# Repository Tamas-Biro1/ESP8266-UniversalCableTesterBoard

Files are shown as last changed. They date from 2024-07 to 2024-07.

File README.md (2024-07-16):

## Overview
The Universal Cable Tester Board is a tool designed to test the continuity and proper wiring layout of any cables up to 32 wires. This project includes the design schematics, PCB layout, firmware, and software for the cable tester.

This board is not a standalone device, it must be connected to a computer (running Windows) through USB cable and the [Cable Analyzer](https://github.com/david-biro/UniversalCableAnalyzer) (opensource) must run on that machine. For more details about the software, click [here](https://github.com/david-biro/UniversalCableAnalyzer).

<p align="center">
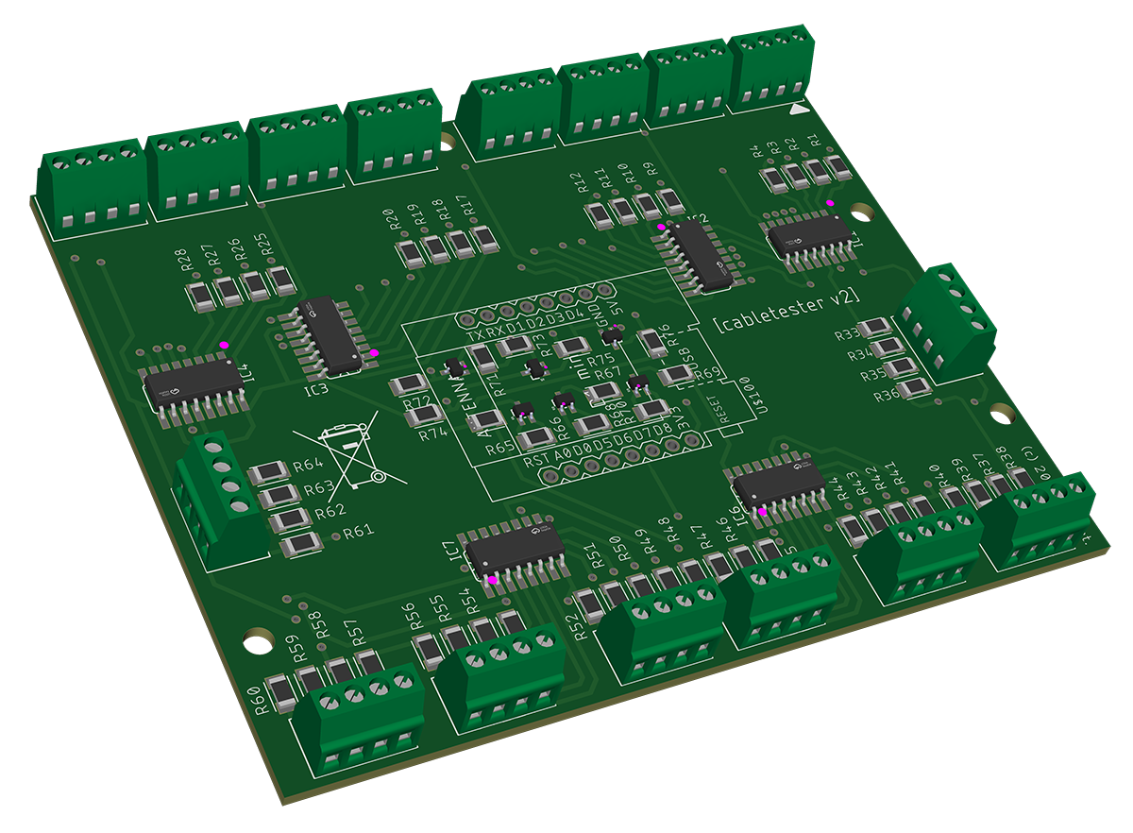
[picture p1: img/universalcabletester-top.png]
Universal Cable Tester
  
</p>

## How it works
### The hardware
The core of the Cable Tester board is a Wemos D1 Mini (ESP8266) microcontroller, which initiates the measurements, collects the test results, and sends the data back to the Cable Analyzer software running on the PC. The Cable Analyzer then evaluates the test results and visualizes them on the GUI. Communication is conducted via a USB connection, utilizing the UART port of the ESP8266, which is connected to a CH340 (or occasionally a CP2104) USB-to-Serial chip. This chip provides USB client connectivity to the ESP8266; therefore, it is required to install a serial port driver on the computer, for example from [here](http://www.wch-ic.com/downloads/CH341SER_ZIP.html).

The measuring mechanism is very simple: when the Cable Tester board receives the `<START>` string via serial, the microcontroller loops through the pins from 1 to 32 and applies 5V to them one by one. In every cycle, it measures and collects the response from the other side accordingly. When it reaches the last pin, it sends the result back to the Cable Tester application to evaluate and visualize.

Example cable layout and its serial output:
<p align="center">
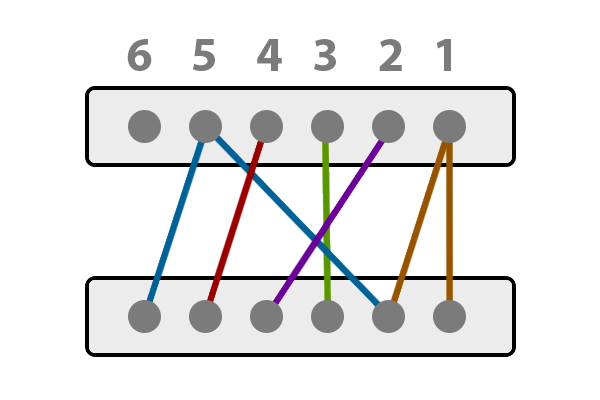
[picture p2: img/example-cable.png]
Universal Cable Tester
  
</p>

  ```
  <RESULT,3,8,4,16,34,0,0,0,0,0,0,0,0,0,0,0,0,0,0,0,0,0,0,0,0,0,0,0,0,0,0,0>
  ```
_Explanation:_ The output string is a comma-separated list of 32-bit integers containing the results for the pins from 1 to 32, listed from left to right respectively. By taking the binary representation of each value, the cable layout can be verified. See:

```
pin:                       [32]                             [1]  
                                       (binary)                  (decimal)
request sent on "A" side:  00000000 00000000 00000000 00000001       1
response got on "B" side:  00000000 00000000 00000000 00000011       3

request sent on "A" side:  00000000 00000000 00000000 00000010       2
response got on "B" side:  00000000 00000000 00000000 00001000       8

request sent on "A" side:  00000000 00000000 00000000 00000100       4
response got on "B" side:  00000000 00000000 00000000 00000100       4

request sent on "A" side:  00000000 00000000 00000000 00001000       8
response got on "B" side:  00000000 00000000 00000000 00010000       16

request sent on "A" side:  00000000 00000000 00000000 00010000       16
response got on "B" side:  00000000 00000000 00000000 00100010       34

request sent on "A" side:  00000000 00000000 00000000 00100000       32
response got on "B" side:  00000000 00000000 00000000 00000000       0

...

request sent on "A" side:  10000000 00000000 00000000 00000000   2147483648
response got on "B" side:  00000000 00000000 00000000 00000000       0
```

To understand this circuit, [here](https://wokwi.com/projects/403145055048695809) is an Arduino playground on **Wokwi** which simulates a straight cable (where pin 1 is connected to pin 1, pin 2 to pin 2, etc.). For better visualization, the wire "connections" are interrupted by LEDs, so when they flash, it means the checking is actually taking place.

Due to the lack of pins on ESP8622, shift registers are used on both side. On the `write` (or "A" side) 4 pcs of [74HC595](https://www.diodes.com/assets/Datasheets/74HC595.pdf) 8-bit serial-in/parallel-out shift registers are used in daisy chain to get 32-bit parallel output from the 32-bit serial input on the DS pin. On the `read` (or "B" side) 4 pcs of [74HC165](https://www.sparkfun.com/datasheets/Components/General/sn74hc165.pdf) parallel-in/serial-out shift registers are used. Between the `write` side and the green terminal blocks, 8 pcs of [IS281-4](https://docs.rs-online.com/c7c9/0900766b81617f80.pdf) NPN type optocouplers are used to isolate wires. 

<p align="center">
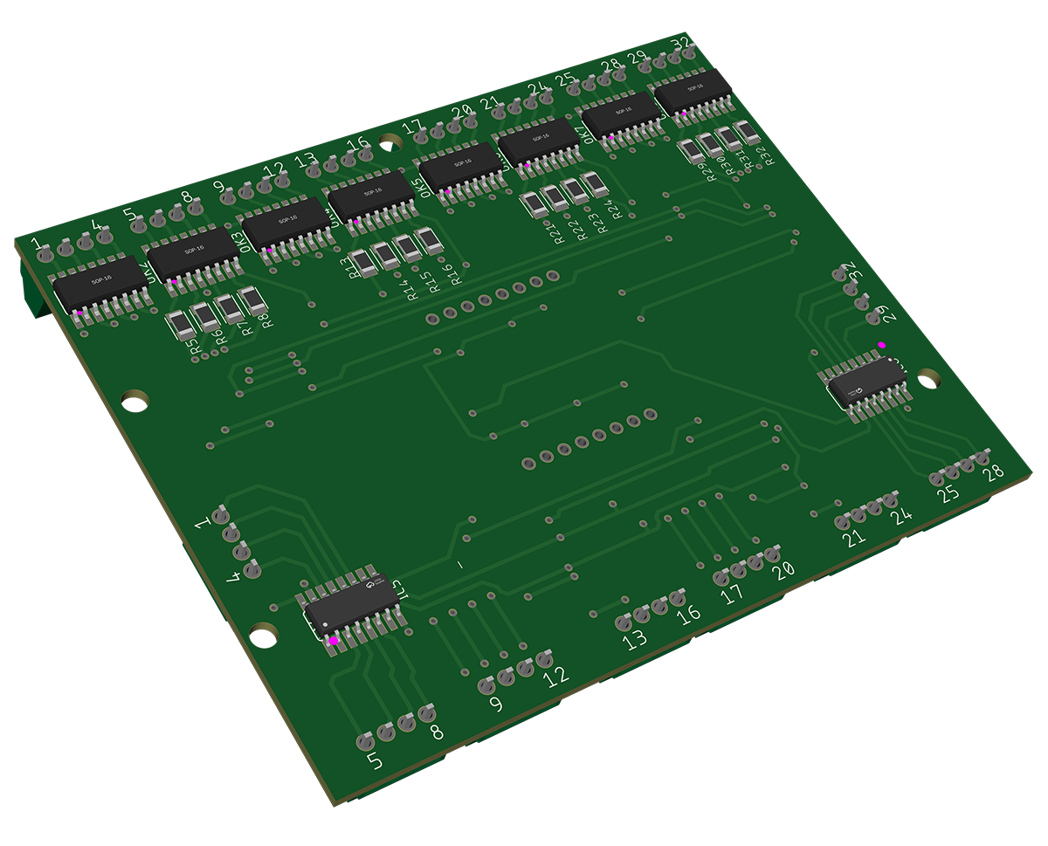
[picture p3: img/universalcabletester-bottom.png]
Universal Cable Tester
  
</p>

### The firmware
The firmware is written in C++ using [PlatformIO](https://platformio.org/)

### Cable connector headers
Currently, only a 24 pin Molex PCB connector is included in this repo, future plans are to add more. Until that, every contributions are welcomed.

## Eagle files
The PCB is double-sided, contains only SMD components (except the 16 pcs through-hole terminal blocks). Here is the list of components:

| Qty | Component | Package |
|---|---|---|
| 4 | 74HC165D | SOIC-16 |
| 4 | 74HC595D | SOIC-16 |
| 8 | IS281 | SOIC-16 |
| 6 | BSS138BKW | SOT-323 |
| 16 | TH Terminal block | XY308-2.54-4P |
| 44 | 10 kΩ | R1206 |
| 32 | 407 Ω| R1206 |

For more details and LCSC partnumbers, please refer the partlist BOM file.

<p align="center">
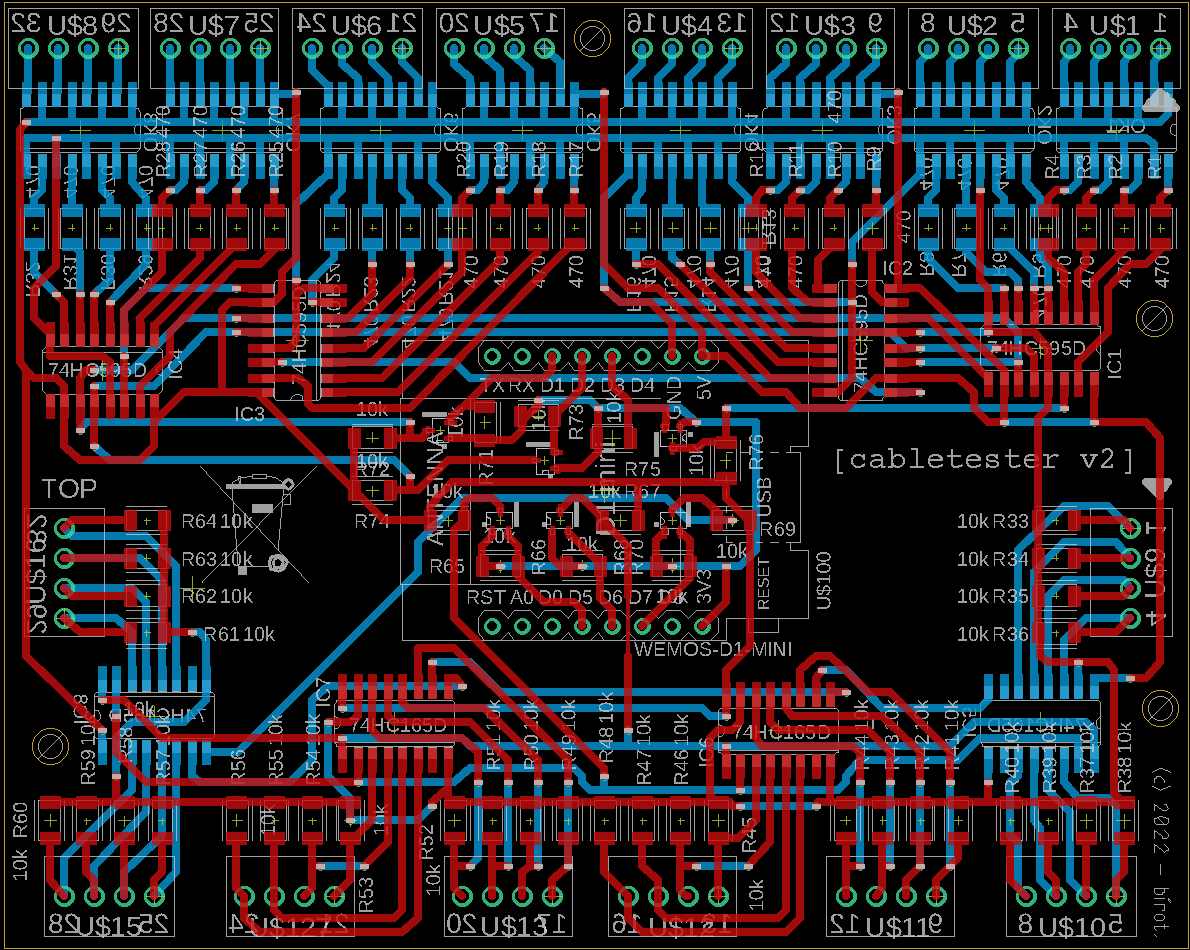
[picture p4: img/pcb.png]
  
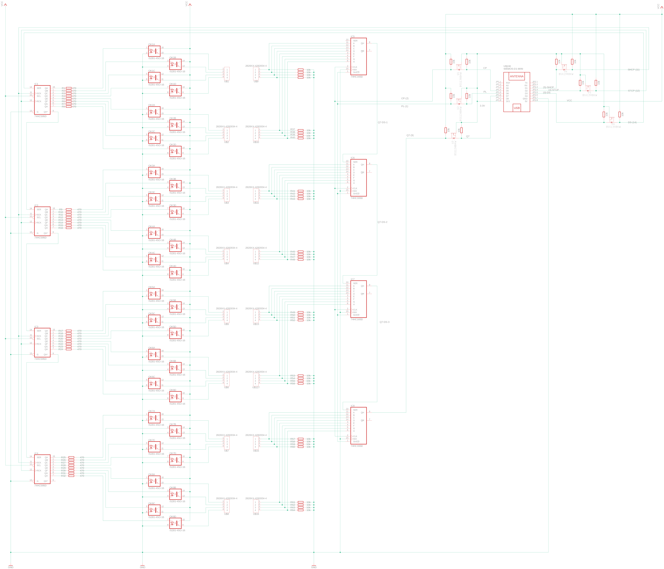
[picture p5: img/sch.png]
  
</p>

## Manufacturing
The final board was created by JLCPCB. For that the Gerber files, the LCSC partlist (BOM) and the Centroid (CPL) files are also included in this repo.

## Contributing
Every contributions are welcomed to improve the Universal Cable Tester. You can fork the repository and submit pull requests for any enhancements or bug fixes.

## License
This project is licensed under the GNU GPLv3 License - see the LICENSE file for details.

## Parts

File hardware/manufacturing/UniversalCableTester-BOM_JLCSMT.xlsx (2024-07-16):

Comment | Designator | Footprint | JLCPCB Part #（optional）
74HC165D | IC5 | SO16 | C5613
74HC165D | IC8 | SO16 | C5613
IS281-4SO-16 | OK1 | SO16 | C89878
IS281-4SO-16 | OK2 | SO16 | C89878
IS281-4SO-16 | OK3 | SO16 | C89878
IS281-4SO-16 | OK4 | SO16 | C89878
IS281-4SO-16 | OK5 | SO16 | C89878
IS281-4SO-16 | OK6 | SO16 | C89878
IS281-4SO-16 | OK7 | SO16 | C89878
IS281-4SO-16 | OK8 | SO16 | C89878
470 | R13 | R1206 | C4502
470 | R14 | R1206 | C4502
470 | R15 | R1206 | C4502
470 | R16 | R1206 | C4502
470 | R21 | R1206 | C4502
470 | R22 | R1206 | C4502
470 | R23 | R1206 | C4502
470 | R24 | R1206 | C4502
470 | R29 | R1206 | C4502
470 | R30 | R1206 | C4502
470 | R31 | R1206 | C4502
470 | R32 | R1206 | C4502
470 | R5 | R1206 | C4502
470 | R6 | R1206 | C4502
470 | R7 | R1206 | C4502
470 | R8 | R1206 | C4502
74HC595D | IC1 | SO16 | C5947
74HC595D | IC2 | SO16 | C5947
74HC595D | IC3 | SO16 | C5947
74HC595D | IC4 | SO16 | C5947
74HC165D | IC6 | SO16 | C5613
74HC165D | IC7 | SO16 | C5613
470 | R1 | R1206 | C4502
470 | R10 | R1206 | C4502
470 | R11 | R1206 | C4502
470 | R12 | R1206 | C4502
470 | R17 | R1206 | C4502
470 | R18 | R1206 | C4502
470 | R19 | R1206 | C4502
470 | R2 | R1206 | C4502
470 | R20 | R1206 | C4502
470 | R25 | R1206 | C4502
470 | R26 | R1206 | C4502
470 | R27 | R1206 | C4502
470 | R28 | R1206 | C4502
470 | R3 | R1206 | C4502
10k | R33 | R1206 | C17902
10k | R34 | R1206 | C17902
10k | R35 | R1206 | C17902
10k | R36 | R1206 | C17902
10k | R37 | R1206 | C17902
10k | R38 | R1206 | C17902
10k | R39 | R1206 | C17902
470 | R4 | R1206 | C4502
10k | R40 | R1206 | C17902
10k | R41 | R1206 | C17902
10k | R42 | R1206 | C17902
10k | R43 | R1206 | C17902
10k | R44 | R1206 | C17902
10k | R45 | R1206 | C17902
10k | R46 | R1206 | C17902
10k | R47 | R1206 | C17902
10k | R48 | R1206 | C17902
10k | R49 | R1206 | C17902
10k | R50 | R1206 | C17902
10k | R51 | R1206 | C17902
10k | R52 | R1206 | C17902
10k | R53 | R1206 | C17902
10k | R54 | R1206 | C17902
10k | R55 | R1206 | C17902
10k | R56 | R1206 | C17902
10k | R57 | R1206 | C17902
10k | R58 | R1206 | C17902
10k | R59 | R1206 | C17902
10k | R60 | R1206 | C17902
10k | R61 | R1206 | C17902
10k | R62 | R1206 | C17902
10k | R63 | R1206 | C17902
10k | R64 | R1206 | C17902
10k | R65 | R1206 | C17902
10k | R66 | R1206 | C17902
10k | R67 | R1206 | C17902
10k | R68 | R1206 | C17902
10k | R69 | R1206 | C17902
10k | R70 | R1206 | C17902
10k | R71 | R1206 | C17902
10k | R72 | R1206 | C17902
10k | R73 | R1206 | C17902
10k | R74 | R1206 | C17902
10k | R75 | R1206 | C17902
10k | R76 | R1206 | C17902
470 | R9 | R1206 | C4502
BSS138BKW | U1 | SOT65P210X110-3N | C5224281
BSS138BKW | U2 | SOT65P210X110-3N | C5224281
BSS138BKW | U3 | SOT65P210X110-3N | C5224281
BSS138BKW | U4 | SOT65P210X110-3N | C5224281
BSS138BKW | U5 | SOT65P210X110-3N | C5224281
BSS138BKW | U6 | SOT65P210X110-3N | C5224281
TERMBLK_254-4N | U$1 | 2828XX-4282834-4 | C915913
TERMBLK_254-4N | U$2 | 2828XX-4282834-4 | C915913
TERMBLK_254-4N | U$3 | 2828XX-4282834-4 | C915913
TERMBLK_254-4N | U$4 | 2828XX-4282834-4 | C915913
TERMBLK_254-4N | U$5 | 2828XX-4282834-4 | C915913
TERMBLK_254-4N | U$6 | 2828XX-4282834-4 | C915913
TERMBLK_254-4N | U$7 | 2828XX-4282834-4 | C915913
TERMBLK_254-4N | U$8 | 2828XX-4282834-4 | C915913
TERMBLK_254-4N | U$9 | 2828XX-4282834-4 | C915913
TERMBLK_254-4N | U$10 | 2828XX-4282834-4 | C915913
TERMBLK_254-4N | U$11 | 2828XX-4282834-4 | C915913
TERMBLK_254-4N | U$12 | 2828XX-4282834-4 | C915913
TERMBLK_254-4N | U$13 | 2828XX-4282834-4 | C915913
TERMBLK_254-4N | U$15 | 2828XX-4282834-4 | C915913
TERMBLK_254-4N | U$16 | 2828XX-4282834-4 | C915913
TERMBLK_254-4N | U$127 | 2828XX-4282834-4 | C915913

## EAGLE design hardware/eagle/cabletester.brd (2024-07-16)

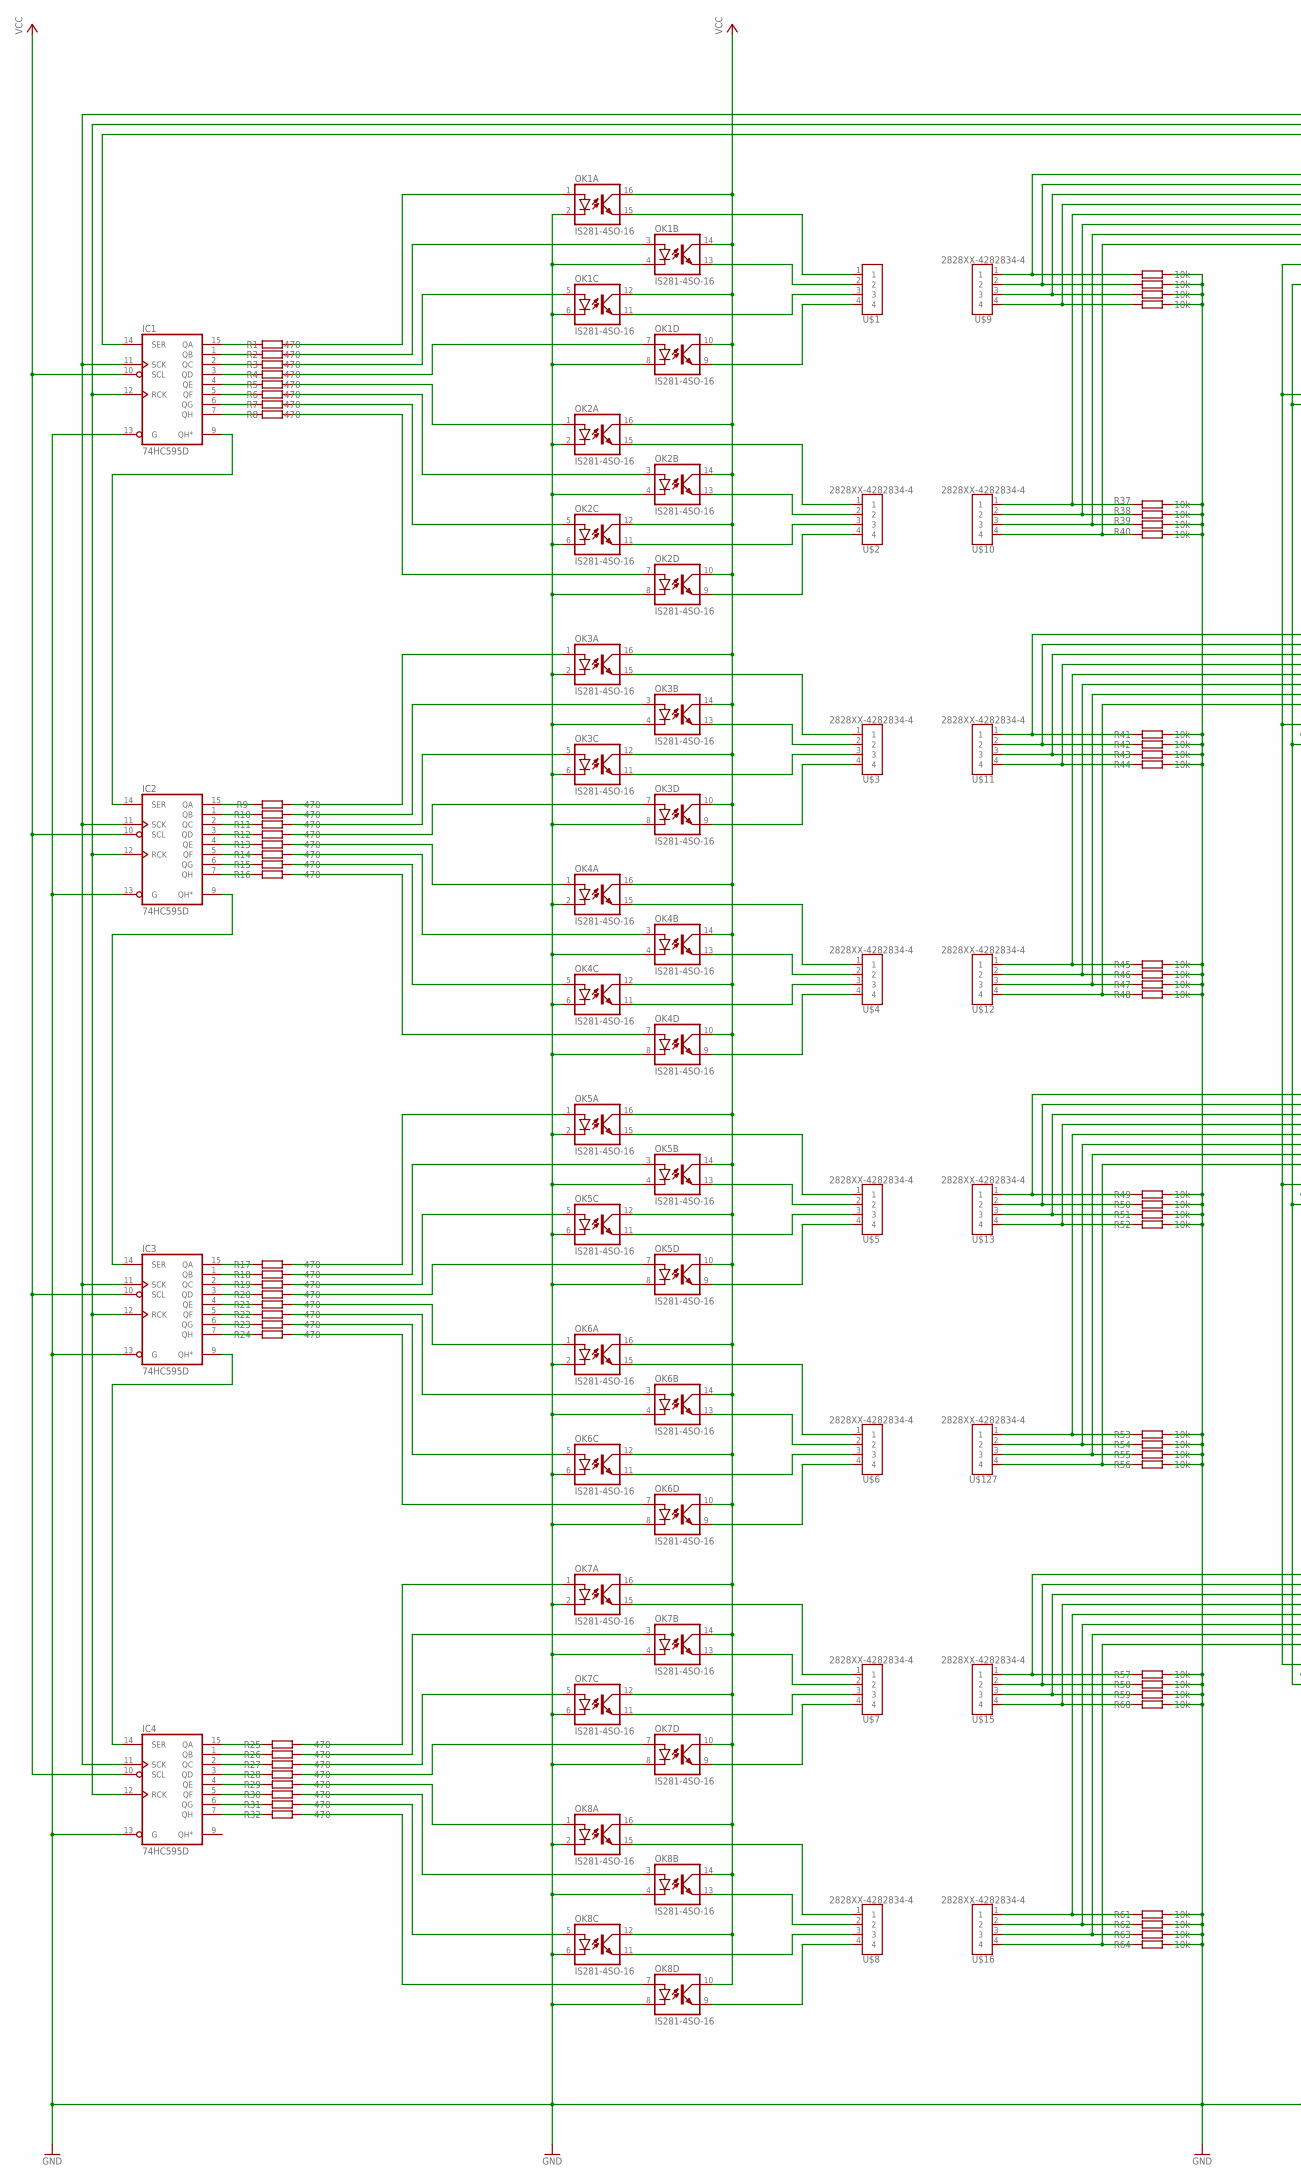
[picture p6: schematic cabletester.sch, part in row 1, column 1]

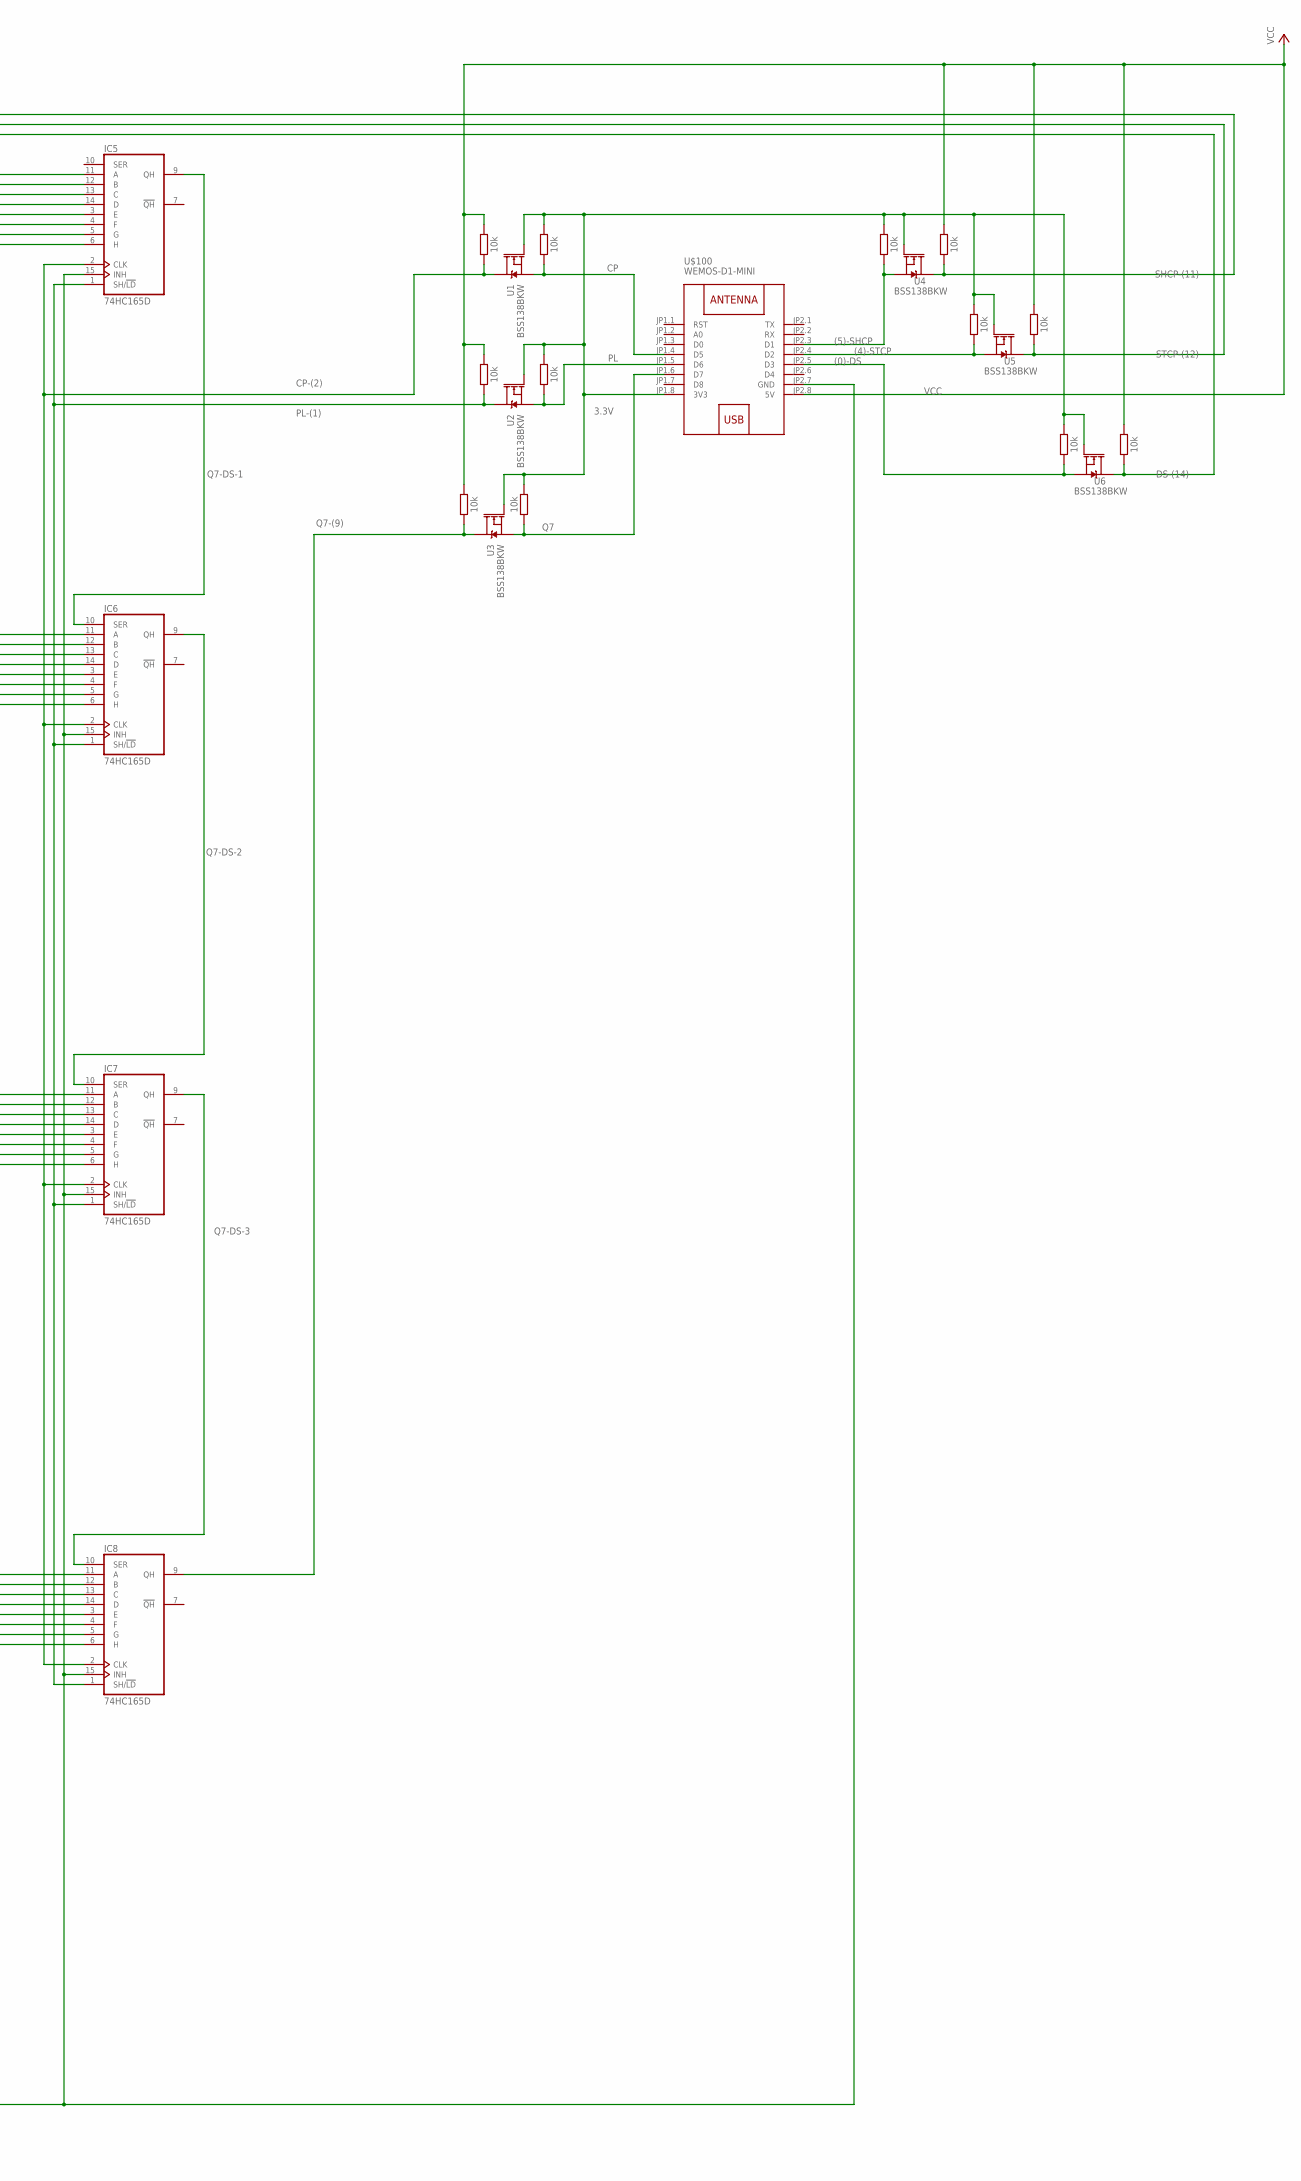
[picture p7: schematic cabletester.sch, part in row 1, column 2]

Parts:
IC1, IC2, IC3, IC4: 74HC595D; SO16
IC5, IC6, IC7, IC8: 74HC165D; SO16
OK1, OK2, OK3, OK4, OK5, OK6, OK7, OK8: IS281-4SO-16; SO16
R1, R2, R3, R4, R5, R6, R7, R8, R9, R10, R11, R12, R13, R14, R15, R16, R17, R18, R19, R20, R21, R22, R23, R24, R25, R26, R27, R28, R29, R30, R31, R32: 470; RESC3216X70
R33, R34, R35, R36, R37, R38, R39, R40, R41, R42, R43, R44, R45, R46, R47, R48, R49, R50, R51, R52, R53, R54, R55, R56, R57, R58, R59, R60, R61, R62, R63, R64, R65, R66, R67, R68, R69, R70, R71, R72, R73, R74, R75, R76: 10k; RESC3216X70
U1, U2, U3, U4, U5, U6: BSS138BKW; SOT65P210X110-3N
U$1, U$2, U$3, U$4, U$5, U$6, U$7, U$8, U$9, U$10, U$11, U$12, U$13, U$15, U$16, U$127: 2828XX-4282834-4; TERMBLK_254-4N
U$100: WEMOS-D1-MINI

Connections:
3.3V: R66.2, R68.2, R70.1, R71.2, R73.2, R75.2, U1.1 (G), U2.1 (G), U3.1 (G), U4.1 (G), U5.1 (G), U6.1 (G), U$100.JP1.8 (3V3)
(0)-DS: R75.1, U6.2 (S), U$100.JP2.5 (D3)
(4)-STCP: R73.1, U5.2 (S), U$100.JP2.4 (D2)
(5)-SHCP: R71.1, U4.2 (S), U$100.JP2.3 (D1)
CP: R66.1, U1.2 (S), U$100.JP1.4 (D5)
CP-(2): IC5.2 (CLK), IC6.2 (CLK), IC7.2 (CLK), IC8.2 (CLK), R65.1, U1.3 (D)
DS-(14): IC1.14 (SER), R76.1, U6.3 (D)
GND: IC1.8 (GND), IC1.13 (G), IC2.8 (GND), IC2.13 (G), IC3.8 (GND), IC3.13 (G), IC4.8 (GND), IC4.13 (G), IC5.8 (GND), IC5.15 (INH), IC6.8 (GND), IC6.15 (INH), IC7.8 (GND), IC7.15 (INH), IC8.8 (GND), IC8.15 (INH), OK1.2 (C), OK1.4 (C), OK1.6 (C), OK1.8 (C), OK2.2 (C), OK2.4 (C), OK2.6 (C), OK2.8 (C), OK3.2 (C), OK3.4 (C), OK3.6 (C), OK3.8 (C), OK4.2 (C), OK4.4 (C), OK4.6 (C), OK4.8 (C), OK5.2 (C), OK5.4 (C), OK5.6 (C), OK5.8 (C), OK6.2 (C), OK6.4 (C), OK6.6 (C), OK6.8 (C), OK7.2 (C), OK7.4 (C), OK7.6 (C), OK7.8 (C), OK8.2 (C), OK8.4 (C), OK8.6 (C), OK8.8 (C), R33.2, R34.2, R35.2, R36.2, R37.2, R38.2, R39.2, R40.2, R41.2, R42.2, R43.2, R44.2, R45.2, R46.2, R47.2, R48.2, R49.2, R50.2, R51.2, R52.2, R53.2, R54.2, R55.2, R56.2, R57.2, R58.2, R59.2, R60.2, R61.2, R62.2, R63.2, R64.2, U$100.JP2.7 (GND)
unnamed: IC4.1 (QB), R26.1
unnamed: IC1.9 (QH*), IC2.14 (SER)
unnamed: IC2.9 (QH*), IC3.14 (SER)
unnamed: IC3.9 (QH*), IC4.14 (SER)
unnamed: OK7.1 (A), R25.2
unnamed: IC1.6 (QG), R7.1
unnamed: IC1.5 (QF), R6.1
unnamed: IC1.4 (QE), R5.1
unnamed: IC1.3 (QD), R4.1
unnamed: IC1.2 (QC), R3.1
unnamed: IC1.1 (QB), R2.1
unnamed: IC1.15 (QA), R1.1
unnamed: IC1.7 (QH), R8.1
unnamed: OK1.1 (A), R1.2
unnamed: OK1.3 (A), R2.2
unnamed: OK1.5 (A), R3.2
unnamed: OK1.7 (A), R4.2
unnamed: OK2.1 (A), R5.2
unnamed: OK2.3 (A), R6.2
unnamed: OK1.15 (EMIT), U$1.1
unnamed: OK1.13 (EMIT), U$1.2
unnamed: OK1.11 (EMIT), U$1.3
unnamed: OK1.9 (EMIT), U$1.4
unnamed: OK2.15 (EMIT), U$2.1
unnamed: OK2.13 (EMIT), U$2.2
unnamed: OK2.11 (EMIT), U$2.3
unnamed: OK2.9 (EMIT), U$2.4
unnamed: OK2.5 (A), R7.2
unnamed: OK2.7 (A), R8.2
unnamed: IC2.1 (QB), R10.1
unnamed: IC2.2 (QC), R11.1
unnamed: IC2.3 (QD), R12.1
unnamed: IC2.4 (QE), R13.1
unnamed: IC2.5 (QF), R14.1
unnamed: IC2.6 (QG), R15.1
unnamed: IC2.7 (QH), R16.1
unnamed: IC2.15 (QA), R9.1
unnamed: OK3.1 (A), R9.2
unnamed: OK3.3 (A), R10.2
unnamed: OK3.5 (A), R11.2
unnamed: OK3.7 (A), R12.2
unnamed: OK4.1 (A), R13.2
unnamed: OK4.3 (A), R14.2
unnamed: OK4.5 (A), R15.2
unnamed: OK4.7 (A), R16.2
unnamed: IC3.6 (QG), R23.1
unnamed: IC3.5 (QF), R22.1
unnamed: IC3.4 (QE), R21.1
unnamed: IC3.3 (QD), R20.1
unnamed: IC3.2 (QC), R19.1
unnamed: IC3.1 (QB), R18.1
unnamed: IC3.7 (QH), R24.1
unnamed: IC3.15 (QA), R17.1
unnamed: OK5.1 (A), R17.2
unnamed: OK5.3 (A), R18.2
unnamed: OK5.5 (A), R19.2
unnamed: OK5.7 (A), R20.2
unnamed: OK6.1 (A), R21.2
unnamed: OK6.3 (A), R22.2
unnamed: OK6.5 (A), R23.2
unnamed: OK6.7 (A), R24.2
unnamed: OK7.3 (A), R26.2
unnamed: OK7.5 (A), R27.2
unnamed: OK7.7 (A), R28.2
unnamed: OK8.1 (A), R29.2
unnamed: OK3.15 (EMIT), U$3.1
unnamed: OK3.13 (EMIT), U$3.2
unnamed: OK3.11 (EMIT), U$3.3
unnamed: OK3.9 (EMIT), U$3.4
unnamed: OK4.15 (EMIT), U$4.1
unnamed: OK4.13 (EMIT), U$4.2
unnamed: OK4.11 (EMIT), U$4.3
unnamed: OK4.9 (EMIT), U$4.4
unnamed: OK5.15 (EMIT), U$5.1
unnamed: OK5.13 (EMIT), U$5.2
unnamed: OK5.11 (EMIT), U$5.3
unnamed: OK5.9 (EMIT), U$5.4
unnamed: OK6.15 (EMIT), U$6.1
unnamed: OK6.13 (EMIT), U$6.2
unnamed: OK6.11 (EMIT), U$6.3
unnamed: OK6.9 (EMIT), U$6.4
unnamed: IC5.11 (A), R33.1, U$9.1
unnamed: IC6.11 (A), R41.1, U$11.1
unnamed: IC5.13 (C), R35.1, U$9.3
unnamed: IC5.14 (D), R36.1, U$9.4
unnamed: IC5.12 (B), R34.1, U$9.2
unnamed: IC6.12 (B), R42.1, U$11.2
unnamed: IC5.3 (E), R37.1, U$10.1
unnamed: IC5.4 (F), R38.1, U$10.2
unnamed: IC5.5 (G), R39.1, U$10.3
unnamed: IC5.6 (H), R40.1, U$10.4
unnamed: IC6.13 (C), R43.1, U$11.3
unnamed: IC6.14 (D), R44.1, U$11.4
unnamed: IC6.3 (E), R45.1, U$12.1
unnamed: IC6.4 (F), R46.1, U$12.2
unnamed: IC6.5 (G), R47.1, U$12.3
unnamed: IC6.6 (H), R48.1, U$12.4
unnamed: IC7.11 (A), R49.1, U$13.1
unnamed: IC7.12 (B), R50.1, U$13.2
unnamed: IC7.13 (C), R51.1, U$13.3
unnamed: IC7.14 (D), R52.1, U$13.4
unnamed: IC7.3 (E), R53.1, U$127.1
unnamed: IC7.4 (F), R54.1, U$127.2
unnamed: IC7.5 (G), R55.1, U$127.3
unnamed: IC7.6 (H), R56.1, U$127.4
unnamed: OK8.3 (A), R30.2
unnamed: OK8.5 (A), R31.2
unnamed: OK8.7 (A), R32.2
unnamed: IC4.2 (QC), R27.1
unnamed: IC4.3 (QD), R28.1
unnamed: IC4.4 (QE), R29.1
unnamed: IC4.5 (QF), R30.1
unnamed: IC4.6 (QG), R31.1
unnamed: IC4.7 (QH), R32.1
unnamed: IC4.15 (QA), R25.1
unnamed: OK7.15 (EMIT), U$7.1
unnamed: OK7.13 (EMIT), U$7.2
unnamed: OK7.11 (EMIT), U$7.3
unnamed: OK7.9 (EMIT), U$7.4
unnamed: OK8.15 (EMIT), U$8.1
unnamed: OK8.13 (EMIT), U$8.2
unnamed: OK8.11 (EMIT), U$8.3
unnamed: OK8.9 (EMIT), U$8.4
unnamed: IC8.11 (A), R57.1, U$15.1
unnamed: IC8.12 (B), R58.1, U$15.2
unnamed: IC8.13 (C), R59.1, U$15.3
unnamed: IC8.14 (D), R60.1, U$15.4
unnamed: IC8.3 (E), R61.1, U$16.1
unnamed: IC8.4 (F), R62.1, U$16.2
unnamed: IC8.5 (G), R63.1, U$16.3
unnamed: IC8.6 (H), R64.1, U$16.4
PL: R68.1, U2.2 (S), U$100.JP1.5 (D6)
PL-(1): IC5.1 (SH/!LD), IC6.1 (SH/!LD), IC7.1 (SH/!LD), IC8.1 (SH/!LD), R67.1, U2.3 (D)
Q7: R70.2, U3.2 (S), U$100.JP1.6 (D7)
Q7-(9): IC8.9 (QH), R69.1, U3.3 (D)
Q7-DS-1: IC5.9 (QH), IC6.10 (SER)
Q7-DS-2: IC6.9 (QH), IC7.10 (SER)
Q7-DS-3: IC7.9 (QH), IC8.10 (SER)
SHCP-(11): IC1.11 (SCK), IC2.11 (SCK), IC3.11 (SCK), IC4.11 (SCK), R72.1, U4.3 (D)
STCP-(12): IC1.12 (RCK), IC2.12 (RCK), IC3.12 (RCK), IC4.12 (RCK), R74.1, U5.3 (D)
VCC: IC1.10 (SCL), IC1.16 (VCC), IC2.10 (SCL), IC2.16 (VCC), IC3.10 (SCL), IC3.16 (VCC), IC4.10 (SCL), IC4.16 (VCC), IC5.16 (VCC), IC6.16 (VCC), IC7.16 (VCC), IC8.16 (VCC), OK1.10 (COL), OK1.12 (COL), OK1.14 (COL), OK1.16 (COL), OK2.10 (COL), OK2.12 (COL), OK2.14 (COL), OK2.16 (COL), OK3.10 (COL), OK3.12 (COL), OK3.14 (COL), OK3.16 (COL), OK4.10 (COL), OK4.12 (COL), OK4.14 (COL), OK4.16 (COL), OK5.10 (COL), OK5.12 (COL), OK5.14 (COL), OK5.16 (COL), OK6.10 (COL), OK6.12 (COL), OK6.14 (COL), OK6.16 (COL), OK7.10 (COL), OK7.12 (COL), OK7.14 (COL), OK7.16 (COL), OK8.10 (COL), OK8.12 (COL), OK8.14 (COL), OK8.16 (COL), R65.2, R67.2, R69.2, R72.2, R74.2, R76.2, U$100.JP2.8 (5V)

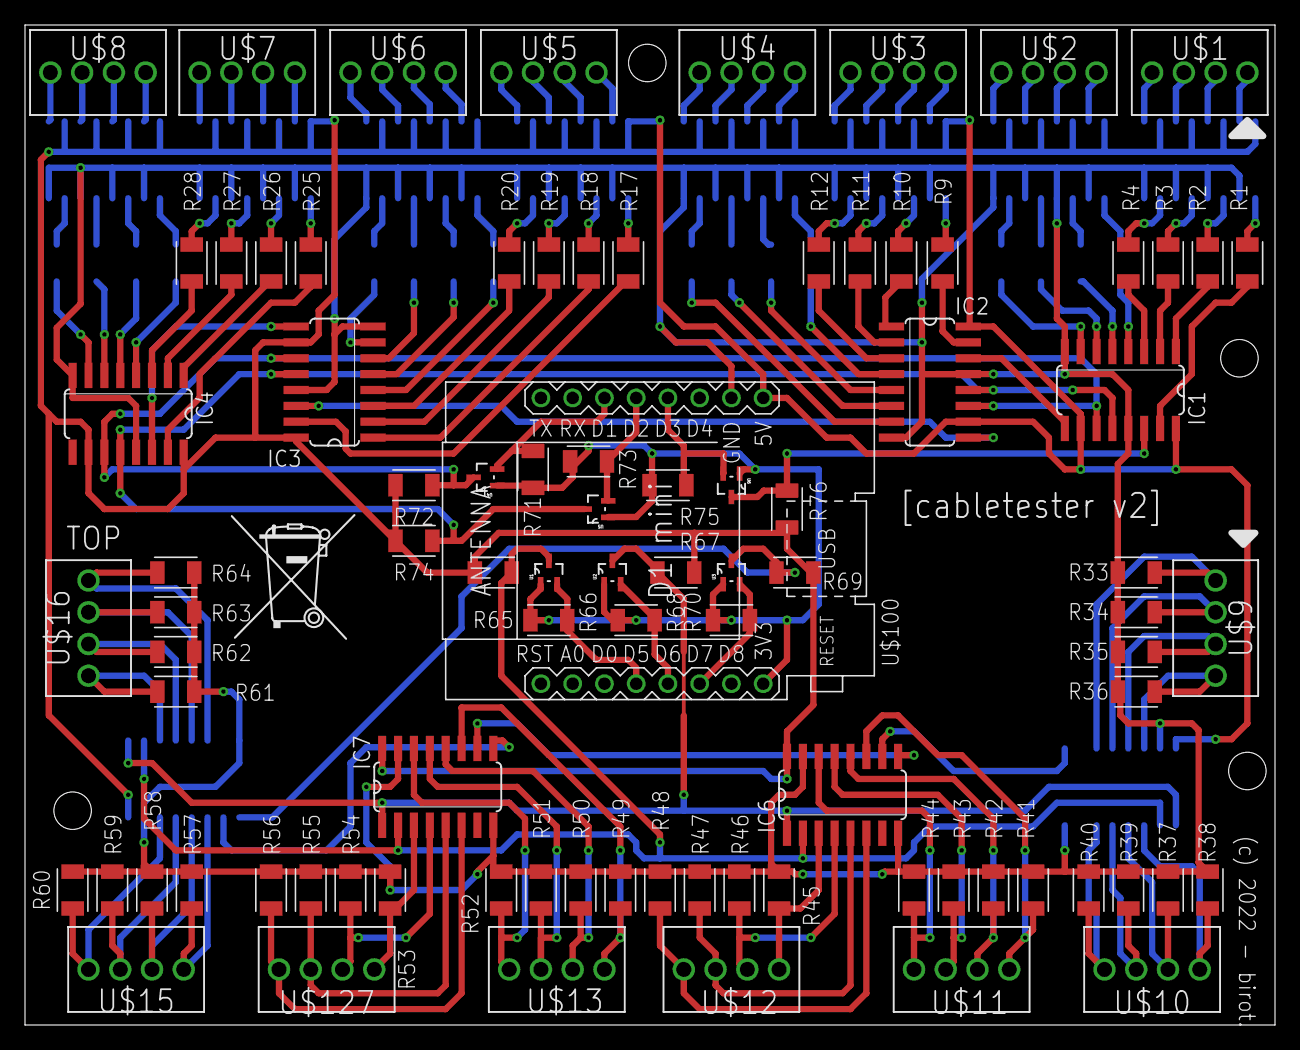
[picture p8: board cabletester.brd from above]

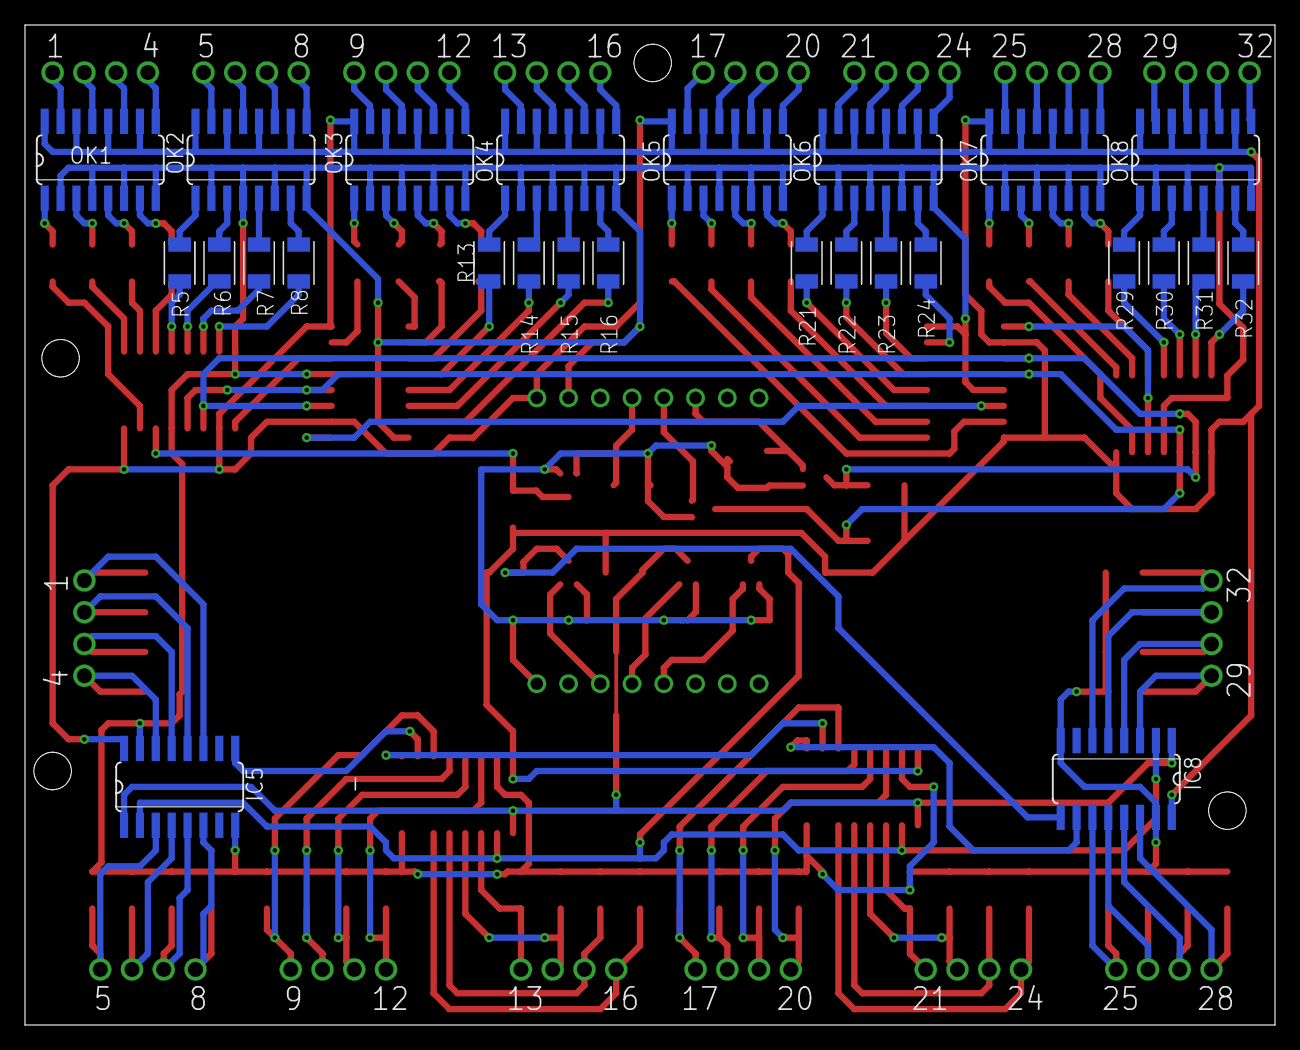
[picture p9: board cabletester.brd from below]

Board: 2 copper layers, 100.0 x 80.0 mm, 116 parts (26 on the bottom side), 149 nets.

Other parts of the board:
U$14: MUELLTONNE_10.00

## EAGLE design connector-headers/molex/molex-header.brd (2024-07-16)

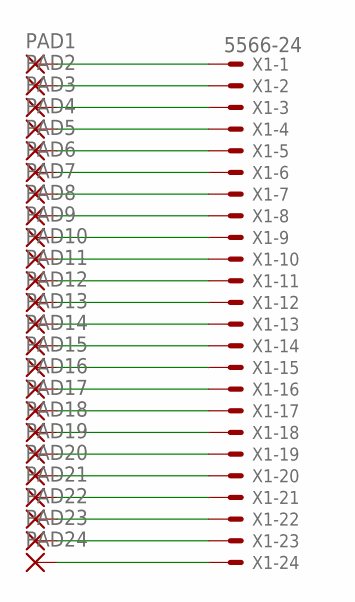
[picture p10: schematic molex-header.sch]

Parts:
PAD1, PAD2, PAD3, PAD4, PAD5, PAD6, PAD7, PAD8, PAD9, PAD10, PAD11, PAD12, PAD13, PAD14, PAD15, PAD16, PAD17, PAD18, PAD19, PAD20, PAD21, PAD22, PAD23, PAD24: SMD5; SMD2,54-5,08
X1: 5566-24

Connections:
unnamed: PAD1.1, X1.1
unnamed: PAD2.1, X1.2
unnamed: PAD3.1, X1.3
unnamed: PAD4.1, X1.4
unnamed: PAD5.1, X1.5
unnamed: PAD6.1, X1.6
unnamed: PAD7.1, X1.7
unnamed: PAD8.1, X1.8
unnamed: PAD9.1, X1.9
unnamed: PAD10.1, X1.10
unnamed: PAD11.1, X1.11
unnamed: PAD12.1, X1.12
unnamed: PAD13.1, X1.13
unnamed: PAD14.1, X1.14
unnamed: PAD15.1, X1.15
unnamed: PAD16.1, X1.16
unnamed: PAD17.1, X1.17
unnamed: PAD18.1, X1.18
unnamed: PAD19.1, X1.19
unnamed: PAD20.1, X1.20
unnamed: PAD21.1, X1.21
unnamed: PAD22.1, X1.22
unnamed: PAD23.1, X1.23
unnamed: PAD24.1, X1.24

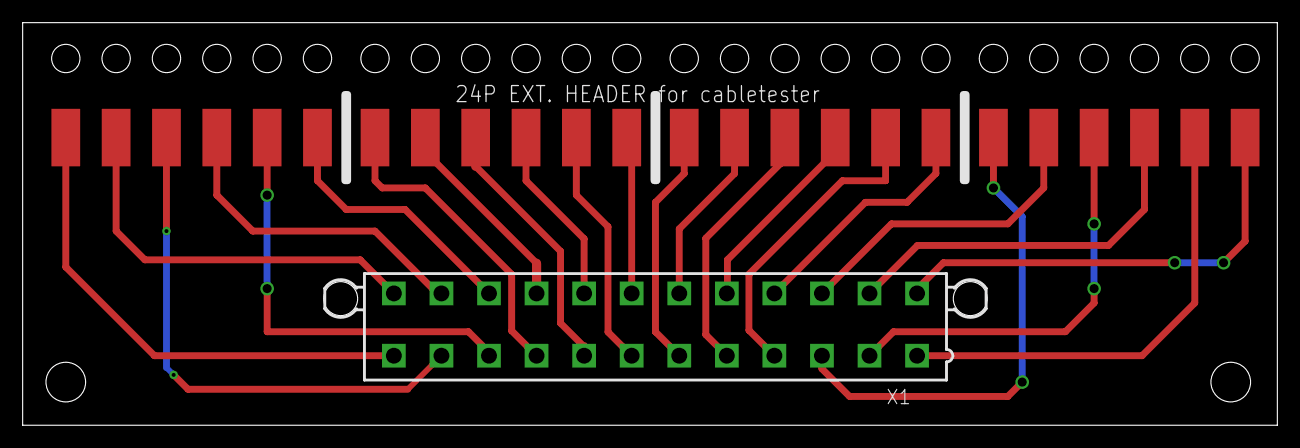
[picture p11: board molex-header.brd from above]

Board: 2 copper layers, 110.8 x 35.5 mm, 25 parts (0 on the bottom side), 24 nets.

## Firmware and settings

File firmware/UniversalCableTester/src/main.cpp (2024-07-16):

/* 32 pin cable tester */
#include <Arduino.h>

#define READ_DATA_PIN 13    // D7 - Q7 pin of 74HC165
#define READ_LATCH_PIN 12   // D6 - PL pin of 74HC165
#define READ_CLOCK_PIN 14   // D5 - CP pin of 74HC165

#define WRITE_DATA_PIN  0   // D3 - DS pin of 74HC595
#define WRITE_LATCH_PIN 4   // D2 - STCP pin of 74HC595
#define WRITE_CLOCK_PIN 5   // D1 - SHCP pin of 74HC595

#define PULSE_WIDTH_USEC 10
#define NUM_SHIFT_REGS 4                // number of 74HC165-74HC595 pairs
#define DATA_WIDTH NUM_SHIFT_REGS * 8   // 32 wire (bit)

#define BYTES_VAL_T unsigned long
BYTES_VAL_T pinValues;

bool registers[DATA_WIDTH];
const byte receiveBufferSize = 32;
char receivedChars[receiveBufferSize];
char tempChars[receiveBufferSize];
char messageFromPC[receiveBufferSize] = {0};
boolean newData = false;

// function prototypes
void clearRegisters();
void setRegisterPin(int index, int value);
void writeRegisters();
BYTES_VAL_T read_shift_regs();

void receiveWithStartEndMarkers()
{
  static boolean receiveInProgress = false;
  static byte index = 0;
  char startMarker = '<';
  char endMarker = '>';
  char receivedData;
  
  while (Serial.available() > 0 && newData == false) {
    receivedData = Serial.read();
    if (receiveInProgress == true) {
      if (receivedData != endMarker) {
        receivedChars[index] = receivedData;
        index++;
        if (index >= receiveBufferSize) { 
          index = receiveBufferSize - 1;
        }
      } else {
        receivedChars[index] = '\0';
        receiveInProgress = false;
        index = 0;
        newData = true;
      }
    } else if (receivedData == startMarker) {
        receiveInProgress = true;
    }
  }
}

/* Reset all register pins */
void clearRegisters() {
  for (int i = DATA_WIDTH - 1; i >= 0; i--) {
    registers[i] = LOW;
  }
}

/* Set an individual pin HIGH or LOW */
void setRegisterPin(int index, int value) {
  registers[index] = value;
}

/* This function is a "shift-out" routine writing the
 * serial Data to the shift register */
void writeRegisters() {
  digitalWrite(WRITE_LATCH_PIN, LOW);
  for (int i = DATA_WIDTH - 1; i >= 0; i--) {
    digitalWrite(WRITE_CLOCK_PIN, LOW);
    digitalWrite(WRITE_DATA_PIN, registers[i]);
    digitalWrite(WRITE_CLOCK_PIN, HIGH);
  }
  digitalWrite(WRITE_LATCH_PIN, HIGH);
}

/* This function is essentially a "shift-in" routine reading the
 * serial Data from the shift register chips and representing
 * the state of those pins in an unsigned long */
BYTES_VAL_T read_shift_regs()
{
    long bitVal;
    BYTES_VAL_T bytesVal = 0;

    /* Trigger a parallel Load to latch 
     * the state of the data lines */
    digitalWrite(READ_CLOCK_PIN, HIGH);
    digitalWrite(READ_LATCH_PIN, LOW);
    delayMicroseconds(PULSE_WIDTH_USEC);
    digitalWrite(READ_LATCH_PIN, HIGH);
    digitalWrite(READ_CLOCK_PIN, LOW);

    /* Loop to read each bit value from the serial out line
     * of the SN74HC165N */
    for(int i = 0; i < DATA_WIDTH; i++)
    {
        bitVal = digitalRead(READ_DATA_PIN);

        /* Set the corresponding bit in bytesVal */
        bytesVal |= (bitVal << ((DATA_WIDTH-1) - i));

        // DEBUG
        //Serial.print(bitVal, BIN);

        /* Pulse the Clock (rising edge shifts the next bit) */
        digitalWrite(READ_CLOCK_PIN, HIGH);
        delayMicroseconds(PULSE_WIDTH_USEC);
        digitalWrite(READ_CLOCK_PIN, LOW);
    }
    return(bytesVal);
}

void setup() {
  pinMode(WRITE_DATA_PIN, OUTPUT);
  pinMode(WRITE_CLOCK_PIN, OUTPUT);
  pinMode(WRITE_LATCH_PIN, OUTPUT);
  clearRegisters();
  writeRegisters();

  // setup() for USB read
  Serial.begin(115200);
  Serial.println("Starting cable testing");

  pinMode(READ_CLOCK_PIN, OUTPUT);   // clock signal, idle LOW
  pinMode(READ_LATCH_PIN, OUTPUT);   // latch (copy input into registers), idle HIGH
  digitalWrite(READ_LATCH_PIN, HIGH);
}

void loop() {
    String result = "<RESULT";
    receiveWithStartEndMarkers();
    if (newData == true) {
        strcpy(tempChars, receivedChars);
        newData = false;
        Serial.println(tempChars);
        if(strcmp(tempChars,"START")==0) {
          for (uint8_t i = 0; i < DATA_WIDTH; i++) {
            setRegisterPin(i, true);
            writeRegisters();
            delay(10);
            pinValues = read_shift_regs();
            result = result + "," + pinValues;
            clearRegisters();
          }
          Serial.print(result);
          Serial.println(">");
        }
    }
}

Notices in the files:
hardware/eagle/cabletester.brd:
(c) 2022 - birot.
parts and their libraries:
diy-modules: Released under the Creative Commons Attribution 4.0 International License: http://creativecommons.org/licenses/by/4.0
